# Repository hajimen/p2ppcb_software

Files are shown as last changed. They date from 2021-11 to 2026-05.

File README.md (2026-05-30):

# Maintenance mode

Now P2PPCB platform is maintenance mode.

You can still buy P2PPCB components, but they are not in stock of 
[DecentKeyboards Etsy shop](https://www.etsy.com/shop/DecentKeyboards).
Please ask me via Etsy system if you need them.

I will maintain P2PPCB platform until Jan 2027. If there is no demand until Jan 2027,
I will stop to maintain.

# P2PPCB platform overview

**P2PPCB platform** is a software / hardware complex for rapid prototyping of 3D-shaped PC keyboards,
offered by [DecentKeyboards](https://www.etsy.com/shop/DecentKeyboards).

With P2PPCB platform, you can design your own 3D-shaped keyboards, like this one:

NTCS

The above is not easy. It takes several hours by a highly skilled operator (me).

But the one below can be done in a few hours by a newbie who has a Windows PC (English) and a broadband connection, without any charge:

Starter Kit Bob

You can build your own design using a 3D printing service, P2PPCB components, and switches / keycaps / stabilizers / etc. as you like.

https://user-images.githubusercontent.com/1212166/204074347-09d51a74-aeb3-4d89-92ee-5701aa64c457.mp4

## No soldering

P2PPCB platform uses single IDC contacts for wiring, as shown here:

Single IDC Ccntacts

Simply push a wire into a contact by a special hand tool.

Special hand tool

Kyocera AVX provides them. Details can be found here:
<https://www.kyocera-avx.com/products/connectors/wire-to-board/single-idc-contact-22-28-awg-9176-400/>

Point-to-point wiring with PCB without soldering, hence the name is "P2PPCB".

Point-to-point wiring is much more flexible than ordinary PCB. 3D-shape is the best example.
Rapid and easy prototyping of ordinary keyboards is also a happy use.
With P2PPCB platform, you don't need to build a dedicated PCB for each design.
Just a 3D-printed frame, and the software helps your CAD operation a lot.

[Socket](https://www.aliexpress.com/item/32959301642.html) connects the switch to the PCB.
There is nothing to solder by yourself, even in the case of split keyboards.
(But if you need to connect a debugger, soldering is required.)

## All softwares are open-source or charge-free for hobbyists

- [keyboard-layout-editor.com](http://keyboard-layout-editor.com) : Open-source
- [Autodesk Fusion 360](https://www.autodesk.com/products/fusion-360/overview): Charge-free for hobbyists
- [P2PPCB Composer F360](https://github.com/hajimen/p2ppcb_software/tree/main/p2ppcb_composer_f360): Open-source
- [QMK firmware](https://qmk.fm/): Open-source

As long as your project stays on a PC screen, there is no charge.

## Switch LED is available

Switch LED

Up to six per keyboard usually.

## MX / Choc V1 / Choc V2 / Gateron LP switches are available

Available switches:

- MX ([Kailh MX](https://www.aliexpress.com/item/32966071689.html) and many other Cherry MX compatible)
- [Kailh Choc V1](https://www.aliexpress.com/item/32959996455.html)
- [Kailh Choc V2](https://www.aliexpress.com/item/4000803757746.html)
- [Gateron LP](https://gateron.com/collections/low-profile-series)

Available stabilizers:

- Cherry-style plate-mount (for MX)
- Coaster (for MX)
- [Kailh Choc V1 stabilizer](https://www.aliexpress.com/item/33039182740.html) (for Choc V1)
- [Choc V2 clip type stabilizer](https://keeb-on.com/products/stabilizer-chocv2) (for Choc V2)
- [Gateron LP](https://gateron.com/products/gateron-low-profile-plate-mounted-stabilizer?VariantsId=10478)

# P2PPCB Composer F360

**P2PPCB Composer F360 (PC0)** is an add-in of Autodesk Fusion 360 (F360) on Windows PC and Mac.
More details can be found here: <https://github.com/hajimen/p2ppcb_software/tree/main/p2ppcb_composer_f360>

## Keycaps

PC0 handles keycaps to check interference and to help your design process.
The following are available on PC0. You can of course put other keycaps on your 3D-printed keyboards.

- XDA (9.5 mm height. CAUTION: There are a lot of "XDA" profiles in the market)
- DSA
- Cherry profile
- OEM profile
- [Kailh Choc V1](https://www.aliexpress.com/item/32979973961.html)
- [Junana MX](https://www.etsy.com/listing/1636124875/blank-junana-mx-keycaps) (New profile from DecentKeyboards)

Only Junana MX can mate with Choc V2 or Gateron LP, normally. In fact DSA 1u can do it in a deep geeky way.
Dig into `P2PPCB Internal/Depot Parts mU0jU/Cap DSA 1u.*` component of your F360 file, and find what to do.

# P2PPCB Components

There are many dedicated components for P2PPCB platform. It also requires general-purpose parts like switches and keycaps.

[DecentKeyboards](https://www.etsy.com/shop/DecentKeyboards) is selling P2PPCB components.
General-purpose parts are at your own choice.

## Mainboard

A mainboard connects the USB to the matrix wires. Comparison chart of the three mainboards:

| |Alice|Bob |Charlotte|
|----|-----|----|---|
|Cost|Bad  |Cheapest|Good |
|Size|Bad  |Smallest|Good |
|Split Keyboard|USART|N/A |Qwiic|
|Qwiic|Yes  |No |Yes  |
|Matrix Size|8x24 + 2x6|12x16|12x16 + 2x3|
|Matrix Wire|Dupont|30 pin ribbon|36 pin ribbon|
|Switch LED|12 |0 |6  |
|Underglow|Yes|No|No|
|USART|Yes|No|No|
|Complexity|Bad|Simplest|Good|

### Alice

Alice

I don't recommend **Alice** in most cases. It is only good for R&D labs that have a high precision and large size 3D printer.
If you use a 3D printing service, go with Bob or Charlotte.

Alice harness kit

Alice accepts female Dupont wire as matrix wire. It is cheaper and more convenient than **Bob** / **Charlotte**'s IDC ribbon cable.
A Dupont wire is not very reliable, but sufficient for trial-and-error iterations of a design process.
A harness kit (the picture above) is available for high reliability, but it is quite expensive.

You might think that IDC ribbon cable is available for Alice. I thought so, too.
But 1.27 mm pitch ribbon cable (common thing) is too thick for a single IDC contact. I could not make it reliable.
(This is a big reason why I made Bob and Charlotte.)

### Bob

Bob

[Purchase from DecentKeyboards](https://www.etsy.com/listing/1609788806/mainboard-set?variation0=4138702941)

**Bob** is the smallest and cheapest but lacks a lot of features.
You can configure most things with VIA <https://www.caniusevia.com/>.
With Bob, you can live without QMK firmware configuration in most cases.

### Charlotte

Charlotte

[Purchase from DecentKeyboards](https://www.etsy.com/listing/1609788806/mainboard-set?variation0=4138702945)

If you need a split keyboard / switch LED / Qwiic connector, **Charlotte** is recommended.
If you go with Charlotte, QMK firmware is a must.

(You may wonder how Charlotte uses I2C for split keyboards. I implemented I2C slave mode
that ChibiOS doesn't have. The code is RP2040 only, sorry.)

## Matrix wire

36-pin 1.00 mm pitch IDC ribbon rainbow cable

[Purchase from DecentKeyboards](https://www.etsy.com/listing/1623836437/matrix-wire)

A matrix wire connects a mainboard to contacts.

Alice accepts a female Dupont wire as a matrix wire. It is a general-purpose part, not a P2PPCB component.
A harness kit for Alice is available as a P2PPCB component, but it is not recommended in most cases.

Bob and Charlotte accept 1.00 mm pitch IDC ribbon rainbow cable as matrix wire. This pitch is not very common.
These are P2PPCB components. When you build a keyboard, peel off the bonds of wires (easy to peel)
and use them as single wires.

## Contact-to-socket assembly

MX, Choc, and Gateron LP socket are available. LED and normal for each socket. So:

- MX LED
- MX normal
- Choc LED
- Choc normal
- Gateron LP LED
- Gateron LP normal

are available.

Contact-to-socket

[Purchase from DecentKeyboards](https://www.etsy.com/listing/1609640258/normal-contact-to-socket-assembly-20pcs)

(You may wonder how an LED and a switch both can be driven / read by only one pair of wires.
By utilizing the forward voltage (Vf) of LEDs. Below its Vf, an LED has no current flow (no light, of course).
We can read a switch by applying a voltage lower than the Vf. To drive an LED, a resistor is connected in series with the switch.
Even when the switch is closed, the resistor produces enough voltage to drive the LED which is connected
in parallel to the switch-resistor. Reading and driving are multiplexed by time division in high frequency like PWM.)

### Single IDC contact push mount

Single IDC Contact Push Mount

To push a wire to a single IDC contact, use this mount. Insert the cuboid end into the switch hole of a frame.
You can get this component by printing the F3D file: `p2ppcb_component_reference/contact-to-socket/Single IDC Contact Push Mount.f3d`.

## Split keyboard kit

Qwiic-to-TRRS

[Purchase from DecentKeyboards](https://www.etsy.com/listing/1609781062/split-keyboard-kit)

Charlotte uses Qwiic (3.3V I2C with Vdd on JST-SH 4-pin connector) for split keyboards.
The Qwiic-to-TRRS assembly is available as a P2PPCB component. TRRS cable is a general-purpose part.

P2PPCB split keyboard kit contains:

- Qwiic-to-TRRS assembly: 2 pcs
- TRRS cable 50 cm: 1 piece

(No P2PPCB component for USART split keyboards of Alice. Connect by female / female Dupont wire or solder a terminal of your own choice.)

You can use the 3D model of TRRS terminal by **Place Misc** command of PC0.

## Adjustable foot kit

Foot spacers

Height comparison

[Purchase from DecentKeyboards](https://www.etsy.com/listing/1623947013/adjustable-foot-kit)

Even with 3D-shaped keyboards, height-adjustable feet are indispensable for many reasons.
Rubber sole is also indispensable. P2PPCB platform has its own foot kit.

# Qwiic-to-FFC adapter kits for trackpad modules

You can embed trackpad modules to your keyboards. Available trackpad models:

- Azoteq ProxSense TPS43 / TPS65 after Dec 2022
- (With light modification) Cirque TM023023 / TM035035 / TM040040

A Qwiic-to-FFC adapter kit contains a Qwiic-to-FFC adapter and the FFC.

Qwiic-to-FFC adapter for Azoteq TPS43/65 after Dec 2022, with overlay for TPS43/65

[Purchase from DecentKeyboards](https://www.etsy.com/listing/1708346877/qwiic-to-ffc-adapter-kit-for-azoteq)

Qwiic-to-FFC adapter for Cirque 12-pin trackpad

[Purchase from DecentKeyboards](https://www.etsy.com/listing/1708366579/qwiic-to-ffc-adapter-kit-for-cirque-12)

The trackpad modules above have FFC connectors. The Qwiic-to-FFC adapters
connect the trackpad modules to the mainboards of P2PPCB.

You can use the 3D models of the adapter and the trackpad modules by **Place Misc** command of PC0.

The Qwiic-to-FFC adapters have DR or RDY contact. They are for power saving. QMK doesn't need them.
In the future, they may be good for wireless keyboards.

# Starter kit

P2PPCB platform requires so many parts to build a real keyboard.

- Special hand tool for single IDC contact (special bit and common handle)
- Mainboard (with screws)
- Contact-to-socket assembly
- Single IDC contact push mount
- Matrix wire
- Adjustable foot kit
- Key switch
- Keycap
- 3D-printed frame
- One Philips and one flat screwdriver :-)

In these parts, difficult-to-reuse is only matrix wire and frame. You can reuse contact-to-socket assembly
up to three times (according to Kyocera AVX. I guess much more actually).

So DecentKeyboards combined them into P2PPCB Starter Kit (except screwdriver). Just by getting this kit,
you can build and test a P2PPCB-based keyboard by hand.

[Purchase Starter Kit Bob from DecentKeyboards](https://www.etsy.com/listing/1631407997/starter-kit-bob)

[Purchase Starter Kit Charlotte from DecentKeyboards](https://www.etsy.com/listing/1617242134/starter-kit-charlotte)

# Technical Details

This repository contains a lot of technical details about P2PPCB platform. You'll need it if you want to go deep.

`p2ppcb_component_reference`: P2PPCB component

`p2ppcb_starter_kit_reference`: P2PPCB Starter Kit

# Discussions

If you have any questions, please feel free to join the discussions:
<https://github.com/hajimen/p2ppcb_software/discussions>

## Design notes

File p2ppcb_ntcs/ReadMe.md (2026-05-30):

# P2PPCB NTCS keyboard overview

NTCS left

NTCS right

**P2PPCB NTCS** keyboard is a reference design of P2PPCB platform. It demonstrates the ability of P2PPCB platform 
to produce elaborate and real-world (not mass-produced) products.

The "NTCS" stands for "Near TKL Conservative Split". 
It is conservative because it accepts ready-made keycap sets (should be row-independent uniform profile like XDA or DSA) 
for common US-ASCII TKL (87-keys) keyboards. It hides several obsolete keys (Pause, Scroll Lock, Print Screen, Caps Lock, Insert, Menu)
under QMK layer, but all other TKL keys are there, so "Near TKL".

You can use it as a reference for your design, as a test specimen to evaluate P2PPCB platform in the real world, 
or just for fun.

# Covered and naked style

P2PPCB platform is mainly for rapid prototyping, so it adopts "naked style" as its usual products. This is an example of the naked style:

Naked style 1

Naked style 2

In naked style, the wires are exposed. It is good for rapid prototyping because it is enough for testing in a lab.
Making a cover is a waste of time and money in this case.

The real world requires a covered style. Once you are confident with your own design in your lab with the naked style, you can bring it 
into the real world with the covered style.

Covered style

P2PPCB NTCS keyboard shows an example of covered style. The structure is thoroughly tested by the real 3D printing results.
I recommend you to imitate the structure on your own design.

# How to assemble

If you feel hard to prepare all parts / components and assemble them, please ask me via email.
The price is $1000 without switches, keycaps, and the shipping charge.

## Parts list

- P2PPCB mainboard Charlotte set: 2 sets
- P2PPCB matrix wire for Charlotte: 2 pcs
- P2PPCB adjustable foot kit: 4 sets
- P2PPCB split keyboard kit: 1 set
- P2PPCB MX normal: 82 pcs of fragment
- P2PPCB MX LED: 2 pcs of fragment
- M2.6 x 7 mm pan-head self-tapping screws for plastic: 16 pcs
- Cherry MX compatible key switch: 84 pcs
- Keycap set, row-independent uniform profile, common US layout TKL (87-key): 1 set
- Translucent 1u keycap: 2 pcs
- Blank 1u keycap: 2 pcs
- Cherry-style plate mount stabilizer for 2u: 4 pcs
- P2PPCB NTCS frames and covers, printed by Somos LEDO 6060: 1 set
- (Optional) Kyocera AVX single IDC contact accessory cap 609176001415000: 168 pcs

## Precision check

Precision checker

You can find these indentations on the covers of NTCS. They are precision checkers for verifying the precision of 3D printing results.
Get an M3 screw or a 3.0 mm drill bit, and try to push it (chuck side or tail) into a gap between three indentations, 
as shown in the figure below.

Precision check

Seven indentations consist a section, and two sections are paired side-by-side. 
The diameter of the green translucent cylinder shown in the figure above is 2.9 mm, or 3.1 mm in the drawings. 
One of the section of a pair is 2.9 mm, and the other is 3.1 mm. Therefore, if a 3D printing 
result is enough precise, you can easily insert a 3.0 mm cylinder into all six gaps of the 3.1 mm section, 
and feel difficult to insert into any gaps of the 2.9 mm section.

The section pairs are installed on the XY, XZ, and YZ planes of a cover because many 3D printers have anisotropy. 
If your 3D printing result fails the test, you may face a problem during assembling. Actually 2.9 mm gaps
can accept 3.0 mm (3D printers tend to have minus tolerance, -20 to -50 μm), but all 3.1 mm gaps must accept 3.0 mm.

## Writing firmware

At the time of shipment, the mainboards' firmware is starter kit's. You need to write the NTCS firmware to the mainboards.
The firmware file is `p2ppcb_charlotte_ntcs.uf2` in this directory.

Unplug the USB, press the BOOTSEL button, and plug USB. You'll find the `RPI RP2` drive on your PC.
Copy the firmware file into the drive. The mainboard will automatically reset itself and become NTCS.

You should write it on both left and right, of course.

## Single IDC contact accessory cap

For P2PPCB starter kit, there are no covers on single IDC contacts. This is reliable enough 
while the keyboard is in the lab. If you find a disconnection, just fix it with the tool.
It is quite rare.

But in the real world, sometimes "quite rare" is not enough. The accessory cap ensures the reliability. 
When you finish an operation test successfully, apply the caps on the contacts. Long nose pliers will help you.

CAUTION: Once you apply a cap, you cannot remove it without damaging the contact-to-socket assembly. 
Check the operation carefully before applying.

CAUTION: If you are using non-genuine matrix wire, the cap may not be applicable. 1.2 mm diameter is the upper limit of the thickness.
The peel-offed wire of a common ribbon cable (1.27 mm pitch) exceeds the limit.

## Tightening screws and warp correction

First of all: Please note that **3D printing material is fragile against small screws such as M2.6**. 
The tightening force should be much less than for normal screws. Just stopping the rattling is enough. 
It cannot withstand too many tightening-loosening iterations. 

I assume that you have already assembled a P2PPCB starter kit. There will be no hard part before
fastening the frame to the cover (please check the operation before fastening). 
The fastening is a bit tricky, because the design is the countermeasure of the warping of the 3D printing results.

Put the frame into the cover, and:

1. Put M2.6 x 7 mm screws into the holes of the cover wall. Don't tighten them, just screw them in a little.
2. Put a M2.6 x 7 mm screw into the hole in the center of the cover bottom. Tighten it mildly.
3. Make sure that the cover bottom is completely flat. If it is not flat, the feet will rattle. 
This is very common because 3D-printing results are always warped.
4. By pushing or pulling the frame to the cover, make the cover bottom flat, and tighten mildly the screws of the wall.

# How to use

The keycaps are row-independent uniform profile. So you can reallocate all 1u keycaps as you like.
Of course you can remap keycode using VIA. The draft definition file for VIA can be found here: 
<https://github.com/hajimen/p2ppcb_software/blob/main/p2ppcb_ntcs/via_keymap.json>

The left and right bodies both have a Micro USB type-B connector. You can choose one whichever you like and connect it to your PC.

The hole on the cover near the USB connector is for BOOTSEL button of Raspberry Pi Pico. You can press BOOTSEL button via the hole
to write new firmware.

The LED keys in front of the space keys are for Caps Lock / Scroll Lock indicator. 
I map LANG2 / LANG1 on them (useful keys for Japanese input) in QMK layer 0. 

The finger assignment shown in the figure below may look strange. 
The "Typing Method" says that you should press the "1/!" key by your pinky finger,
but I think this is outdated rubbish from the age of non-electric typewriters and professional typists. They didn't use wrist rests 
because they had to hit the keys with an adequate even force, like a pianist. If the hitting force is uneven, the thickness of the letters 
will be uneven. This was not considered the workmanship of a professional typist. So they hit the keys with their shoulders and arms, 
not with palms and fingers. In this case, the shortness of the pinky finger is not a 
problem because the upper arm moves and covers all the keys on a keyboard. 
Also, professional typists didn't develop sentences in front of a typewriter because there was a manuscript to type. 
No revising or editing, of course. In front of a typewriter, they just typed without stopping. 
There was no room for wrist rests, like on a piano.

Today we live on another planet. 
NTCS has built-in wrist rests. It doesn't assume shoulder-and-arm typing. Long fingers should press distant keys.

Finger Assignment

# The design process of NTCS

P2PPCB platform is for rapid prototyping. So I guess you are going to start a design process with it.
The F3D files show the final result, not the process. Let's see the story.

## Starting point 1: TRON keyboard TK1

The 1980s was the golden age of bizarre keyboards. The pinnacle is TRON keyboard TK1, 1991.

TK1

Cited from SAKAMURA Ken, Keyboard Dangi 7, bit (1990) Vol. Dec.

TK1 has its long story. I only enumerate the ideas what I stole from it.

- 10° twist along front-back direction and built-in wrist rests

These two ideas are closely related. 10° twist along front-back direction requires uncommonly high-profile wrist rests 
because the keytop altitude of the inner area is much higher than common keyboards.
Built-in wrist rests can be uncommonly high-profile.

- Wedge-shaped gaps between keytops

My dear keyboard people, please stop filling a keyboard with keytops. This is a quite common mistake
in the industry. Key separation (the ability to press a key without interfering with other keys) is much more 
important than keytop largeness, and key separation requires gaps between keytops.
Your habit may say "Gaps between keytops are ugly". Please break that habit now.

NTCS's wedge angle is much sharper than TK1's. TK1's angle is more bizarre and attractive, but I've come to 
the conclusion that it is not good for typing.

- Small space key and Shift keys with thumbs

These ideas were very common even before TK1. Maltron's keyboard in 1980 had a small space key.
Fujitsu's "親指シフト" (Thumb Shift) keyboard in 1980 had Shift keys with thumbs (the space key was also small). 

- Arrow keys under the main cluster (right side only)

Symmetrical arrow keys are the great charm of TK1. I tried to mimic this by placing Home / End / PgUp / PgDn instead of 
red arrows on the left hand part, but when I tested the layout with several prototypes, I realized that this is a bad idea. 
All navigation keys should be assigned to the right hand, because the left hand should focus on copy / paste.

- How about other ideas?

As you can see, I didn't adopt many ideas in TK1. Symmetrical and column-staggered layout, 
built-in drawing tablet, 3-bank typewriter style shift (left and right Shift keys work differently), 
16 mm pitch, etc. Yeah TK1 is the pinnacle of the bizarre keyboards of the 1980s. 
I miss these ideas, but this is a design process.

## Starting point 2: Ready-made keycap set

I am running a custom keycap shop [DecentKeyboards](https://www.etsy.com/shop/DecentKeyboards). 
I can print any legends on white PBT blank keycaps. But such custom keycaps can distract 
attention from the capabilities of P2PPCB platform. NTCS is a reference design for P2PPCB platform, 
not an ultimate keyboard.

(Besides, an ultimate keyboard requires a new ecosystem. OS, applications, common practice, 
users, developers, hardware and its supply chain. 
TRON keyboard TK1 was a part of such a new ecosystem "BTRON", but it failed. From this experience, 
I think that an ultimate keyboard will not be profitable, not widely available, not even very good for most people in the real world, 
even if it is mass-produced and its price is around ordinary keyboards. An ultimate keyboard is like 
an exotic car. Its price may be several hundred times of ordinary products, but it is inferior to ordinary products 
in most respects, even without taking the price into account.)

Swapping keycaps is a great hobby. It is much harder with custom keycap-based keyboards. 
A ready-made keycap set is a great product of the existing ecosystem.

## Starting point 3: Keyboard shortcuts of Windows applications

Actually, I'm not a big fan of keyboard shortcuts. Of course I use them heavily, but because of that, 
my pinky finger hurt often (now I am free of the pain with NTCS). From a productivity standpoint, 
keyboard shortcuts are negligible IMHO. I use them just because I'm impatient with using a mouse.

Not all the people (including keyboard people) are so impatient. Prioritizing keyboard shortcuts is an important 
decision, because it completely changes the design.

For example, by prioritizing keyboard shortcuts, all modifier keys should be easy to press simultaneously, 
in any combination, with one hand.
(I think multiple pressing of modifier keys is 
a bad idea in the existing ecosystem. Commands should be invoked when the keys are released, just like mice and touchscreens. 
But NTCS is not an ultimate keyboard).
Because of this requirement, 
yet another modifier key (i.e. QMK layer) is hard to use heavily. Ctrl+Shift+F5 is a very familiar shortcut in Visual Studio, 
but if F5 is hidden by yet another modifier (YAM) key, Ctrl+Shift+YAM+5 should be easy to press. 
In Japanese typing, F7 is a very frequently used key. YAM+7 should be as easy to press as Shift+7. 
I think it is impossible to fulfill all of these requirements under all of the prerequisites above.

Under different prerequisites, heavy use of YAM key can be a good design because it can reduce the number of keys on a keyboard. 

## Starting point 4: Stateless (as far as I can)

I hate intangible states. The downfall of keyboards started when the latching mechanism of Caps Lock key was substituted by LEDs.
One-shot modifier of QMK is a kind of intangible states.

## Other ideas stolen from various keyboards

- Del key at the left edge

The idea comes from Symbolics keyboard (namely Space-cadet). The RUB OUT key is a legend.

- Esc key at the left top corner of the main cluster

This was common before the dominance of IBM Model M layout. I'd like to name HHKB as the resistance movement against
the dominance.

## Iteration 1

https://user-images.githubusercontent.com/1212166/207766975-fe80b625-9c89-4bb3-ab00-f115f13a7b42.mp4?raw=true

The first trial. Left hand only, naked style, custom keycap based. In this iteration, I didn't adopt the start point 2.

I got a lot of findings in this iteration. 

- Thumb keys should be tilted in the opposite direction of the other keys.
- Wrist rests should be uncommonly high-profile, because the keytop altitude of the inner area is 
much higher than common keyboards.
- Pinky finger keys should be more front.

## Iteration 2

https://user-images.githubusercontent.com/1212166/207769963-8871a65c-baf6-4fd5-8fc1-cc160b2b6ee9.mp4?raw=true

The first trial of the covered style. I adopted the start point 2 from this iteration.

- Small space key should be in front of V. Shift key should be the right neighbor of the space key.
- Q should be pressed by a ring finger.
- Thumb keys should be lower.
- Ctrl key should be a thumb key.

I don't mention the problem of the covered style. Just imitate the conclusion shown in the F3D files of NTCS.
And I don't mention the right hand part too. It will be redundant.

## Iteration 3

https://user-images.githubusercontent.com/1212166/207800112-49950f18-dee0-47fb-89b6-9756c5d27d19.mp4?raw=true

https://user-images.githubusercontent.com/1212166/207801987-bb7279e0-d1bd-43f7-8470-23f2b017d544.mp4?raw=true

The first trial of built-in wrist rests. I thought of taking a video at this time.
The material is SLA of WENEXT. Built-in wrist rests take up a lot of space,
and it makes 3D printing much more expensive.

- The position of the Alt key is not a good idea.
- Pressing the space key interferes with End key.
- The wrist rests are too long in front-back direction.
- Shift and Ctrl keys should be a bit further back.
- Ctrl key should be 1 mm higher.
- Q row of pinky finger section should be slightly higher for key separation.
- Tab key is too far for pinky finger.

## Iteration 4

https://user-images.githubusercontent.com/1212166/207805898-d4af1ae7-47c4-46dc-a097-f8915beb6a94.mp4?raw=true

https://user-images.githubusercontent.com/1212166/207806336-694a83c3-6f9b-410a-8993-eb757cfd567e.mp4?raw=true

- Shift key should be further front.
- LANG1 should be lower. Pressing the Ctrl key interferes.
- Symmetrical layout of arrow keys (Home / End / PgUp / PgDn - Left / Right / Up / Down) is a bad idea.

## Iteration 5

https://user-images.githubusercontent.com/1212166/207811766-837e6841-0c39-4954-b991-4490d437edb7.mp4?raw=true

https://user-images.githubusercontent.com/1212166/207813334-f48241b7-b52c-4ad7-b488-d3c9fbc1e20a.mp4?raw=true

In this iteration, the material is MJF PA12 black.

- Function keys interfere with my palm. The function key cluster should not tilt.

## Iteration 6

This is the last iteration worth mentioning. I have done many more, but the findings are trivial.
This iteration is not the final result, but it is close enough for the purpose of this story.

https://user-images.githubusercontent.com/1212166/207817193-05dbc5cd-c3d1-442c-9eca-ad06bcb6c566.mp4?raw=true

https://user-images.githubusercontent.com/1212166/207817925-683ccf40-5cc8-40d5-9adb-0121a6b742cf.mp4?raw=true

- The key angle surface should be finely tuned.

# How to imitate the structure of NTCS

It is far from straightforward. If you feel it is too tedious, please ask me. I can make a covered style 
from your naked style F3D file. It costs, of course.

The basic story is the Fill/Hole method. You should do the method manually to the cover.
In the F3D file of NTCS, on the object browser, expand `P2PPCB Internal/Foot Placeholders mU0jU/Foot A_FL:1/Foot_P:2/Bodies`.
You'll find a `Foot Fill Cover` body. `Cover Boss.*/Bodies` and `Adjust Boss.*/Bodies` also have bodies with such names. 

The **Regex Select** command will help you. You can see the results of the command 
in the "Selection Sets" of the object browser.

`P2PPCB Internal/Depot Parts mU0jU/Switch MX_P:1/Bodies/MF/Switch Fill.*` is a very important trick that is hard to 
comprehend. See the timeline of the F3D file step by step. The fill body of `Switch MX_P` is modified from the original 
before the **Fill** command is executed. The modification makes it possible to connect a bridge body to a switch 
fill body using the **Extrude** command.

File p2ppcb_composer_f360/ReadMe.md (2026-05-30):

# Maintenance mode

Now P2PPCB platform is maintenance mode.

You can still buy P2PPCB components, but they are not in stock of 
[DecentKeyboards Etsy shop](https://www.etsy.com/shop/DecentKeyboards).
Please ask me via Etsy system if you need them.

I will maintain P2PPCB platform until Jan 2027. If there is no demand until Jan 2027,
I will stop to maintain.

# P2PPCB Composer F360

**P2PPCB Composer F360 (PC0)** is an add-in of Autodesk Fusion (f.k.a. Fusion 360). It helps you to design your own keyboard
based on P2PPCB platform <https://github.com/hajimen/p2ppcb_software>.
I, DecentKeyboards <https://www.etsy.com/shop/DecentKeyboards>, provide P2PPCB platform.

DISCLAIMER: PC0 is slow for a large keyboard, so far. Initial **Load KLE** command can take several minutes.
Please start with making small studies and get a good grasp of the time consumption.

## Requirements: Just designing a Keyboard

- Windows PC or Mac

- Autodesk Fusion (F360) <https://www.autodesk.com/products/fusion-360/overview>

Autodesk Fusion is a proprietary 3D CAD. Autodesk generously offers charge-free plans for hobbyists so far.

Why does F360 mean Autodesk Fusion? Autodesk has rebranded Fusion 360 to Fusion in 2024. I am too lazy to follow
such pastime. I will call it Fusion 360 or F360 in all other places.

## Requirements: Building your own design

- A 3D printing service shop

As the printing material, HP Multi Jet Fusion (MJF) <https://www.hp.com/us-en/printers/3d-printers/products/multi-jet-technology.html> and
Somos® Ledo 6060 with sanding are well tested. In many cases, the latter is much cheaper.

IMPORTANT: The modeling assumes -20 to -50 μm tolerance. MJFs are made with this tolerance.
Ledo 6060s with sanding also. But Ledo 6060s **without sanding** has almost zero tolerance.
It doesn't fit. Choose "Surface finish: Sanding" if you use Ledo 6060.

There are many 3D printing service shops of MJF or Ledo 6060 in the world. 
[Shapeways](https://www.shapeways.com/) (North America and Europe), 
[DMM.make](https://make.dmm.com/) (Japan), [WENEXT](https://www.wenext.com/) (China),
[JLCPCB](https://jlcpcb.com/) (China) etc.
Pick a good one for you. I always use JLCPCB.

In most cases, 3D printing service shop will give you a warning about too thin walls. In most cases,
I don't recommend you to fix it. You must have the ability to identify real limits if you want to make
an elaborated design. Failure teaches success.

- P2PPCB components by DecentKeyboards <https://www.etsy.com/shop/DecentKeyboards>

PC0 is free, but P2PPCB components aren't :-).

- QMK Firmware <https://qmk.fm/>

You need your own firmware for your own design. PC0 will help you, but you need to be well informed about QMK.

P2PPCB mainboards require special code for their own hardware. I have prepared the codebase which handles the custom hardware:
<https://github.com/hajimen/qmk_firmware/tree/p2ppcb>. Fork the `p2ppcb` branch for your own design.

- Switches, keycaps, stabilizers

If you need custom printed keycaps for your own design, contact DecentKeyboards <https://www.etsy.com/shop/DecentKeyboards>.
I can make custom printed PBT keycaps. The total cost will be from about $30.

## Install

Download the latest release file from here: <https://github.com/hajimen/p2ppcb_software/releases>

Unzip the release file, run F360, click the **UTILITIES** tab -> click **+** -> Choose **Script or add-in from device**.
Select the `p2ppcb_composer_f360` directory in the unzipped release file.
Find `P2PPCB Composer F360` row and click the **Run** column's slide switch.
Now the "P2PPCB" tab should appear in the F360 menu.

## Overview of operations

1. Design your own key layout using KLE <http://www.keyboard-layout-editor.com/> and download the result in JSON. The file is a KLE file.

You can include QMK keycodes in your KLE file. The details are later.

2. Design the height/angle of the keys using F360 surface(s).

The F360 surface is a **skeleton surface**. You also need a F360 construction plane as a **layout plane**.
You can specify a **key angle surface** to create a stepped ("staircase") profile keyboard with uniform profile keycaps (DSA/XDA, etc.).
A **main surface** in the **Initialize** command dialog is both skeleton and angle.

You can get an example set of them from a scaffold set built in PC0.
Click the green **P2P/PCB** command icon in the P2PPCB tab and check the **Generate a scaffold set** checkbox in the command dialog.

https://user-images.githubusercontent.com/1212166/205190284-dbbb6a80-51aa-4bd7-b1e0-33d8e4ddc5c1.mp4

3. Start a P2PPCB project

Specify the main preference of key switch, cap, stabilizer, vertical alignment, etc.
The F360 file holds the preference.

You can run this command more than once.

https://user-images.githubusercontent.com/1212166/205190521-6bdee0ec-76c7-4ee5-b622-5411ba3257b6.mp4

4. Load KLE file

This can take several minutes for a large keyboard. F360 is not very suitable for P2PPCB Composer, but you don't want to pay
thousands of USD for CATIA, I guess.

5. Adjust any key

Of course you can move any key.

https://user-images.githubusercontent.com/1212166/205190738-955e6beb-f937-490e-a4c4-32c4ce18899b.mp4

You can also change the switch / cap / stabilizer / etc. of each key by using the **Change Key** command.
A bit bizarre behavior can occur in this command. See the video below.

https://user-images.githubusercontent.com/1212166/205191054-84a16ef2-c920-4fa9-a5d0-66a4c00a2914.mp4

6. **Fill** command

A generated frame doesn't have holes for keys yet. It is intended for the Fill/Hole method. The details are later.

https://user-images.githubusercontent.com/1212166/205191342-d7a71c5c-0b93-40e0-bb5d-ce35f1fff37d.mp4

7. Place mainboard and feet

You can run this command more than once. In most cases, you'll need to do many to place the feet.

In most cases, you will need to check for interference. It is extraordinarily slow. Use it carefully.

https://user-images.githubusercontent.com/1212166/205191446-48d868da-c83e-4557-8093-cd8c0a0816a8.mp4

8. Connect mainboard/feet bosses to a frame

You need to do this step through F360's features like loft, extrude, etc.

https://user-images.githubusercontent.com/1212166/205191579-d20d2189-508d-4ecd-a077-7d0353ef2241.mp4

9. **Hole** command

It creates a 3D printable solid body. Right-click the body in the browser, select **Save As Mesh**, select STL and click OK.
Send the STL file to your 3D printing service shop.

https://user-images.githubusercontent.com/1212166/205191677-80e63a34-99b5-444a-b3b5-ab5381502606.mp4

10. There is a thin wall? Oh...

3D printing cannot print thin walls. This often occurs in elaborated designs.
Some 3D printing service shops will accept such STL files if you take on all the risks. Some don't.
In that case, you have to remove them yourself (or ask another shop).

## Bridge and Fill/Hole - MF/MEV method

Switches, stabilizers, and screws should be fastened to their holes in the frame. Such holes must be free of obstructions,
otherwise parts will get stuck.

On the other hand, a frame itself is not so strict about defects. A frame should be strong, rigid,
and have essential areas to hold parts (such as internal screw threads).
Except for the essential areas, a frame can have some defects (voids) to some extent. Let's call such
non-essential areas which surrounding essential areas as "support areas".

PC0 adopts the Fill/Hole method to form a frame. Fill: create a solid. Hole: cut the solid.

How to create a solid? By connecting essential+support areas to each other. Where the key layout is dense,
the essential+support areas of the keys overlap. In this case, a simple "join" operation is sufficient.
Where the key layout is sparse, a **bridge** should connect the essential+support areas.
A bridge is a board parallel to the skeleton surface. 
By joining essential+support areas and a bridge, a solid is created. This is **Fill**.

Cutting the solid will be obvious. Holes must be void without obstructions,
so the Fill/Hole method doesn't allow fill-after-hole. This is **Hole**.

After Fill/Hole, we need to check that essential areas are filled without defects. The area that must be filled is **MF** (must-filled).

Hole areas don't always match their parts. Two parts cannot occupy the same area, but two insert paths can do. 
An insert path is occupied by a part during assembly, but is empty after the part is assembled.
A typical case is Cherry-style stabilizer's wire. Thus, a hole area can be larger than its part.
To know the area of a part itself, and to check the interference of parts with each other,
we need the **MEV** (must-exclusively-void) area in addition to the hole area.

To reduce the inference check computation, there is **Territory**. It declares the outer edge of fill-hole areas of a part.
You won't find it in normal operation.

**Placeholder** will be obvious. It is for developers only too.

## QMK keycodes in your KLE file

QMK keycodes can be found here: <https://github.com/hajimen/qmk_firmware/blob/p2ppcb/docs/keycodes.md>

By including the keycodes in your KLE file, P2PPCB can help you a lot. Just write the keycode (of layer 0) in the the front-left legend of the key.
The front-center legend is layer 1, and the front-right legend is layer 2. You can see the example in
`scaffold_data/starter-kit.json`.

## Keyboard matrix

Keyboard matrix: <https://github.com/hajimen/qmk_firmware/blob/p2ppcb/docs/how_a_matrix_works.md>

P2PPCB Bob/Charlotte uses S and D instead of row and col. QMK's row and col are independent of the current direction 
(ROW2COL and COL2ROW are both capable), but S and D are always S to D.

By assigning a matrix, and by including the keycodes in your KLE file, you can generate route data
(QMK keymap and wiring diagrams) and VIA keymap.
Without them, your life will be much harder. Use the **Assign Matrix** command and the **Generate Route** command in the P2PPCB tab.

Generating route data for split keyboards is not supported. You need to combine two keymaps into one by yourself.
The example is shown at <https://github.com/hajimen/qmk_firmware/blob/p2ppcb/keyboards/p2ppcb/charlotte/keymaps/ntcs/keymap.c>.

## Show all available caps

There are several `test.json` files in `p2ppcb_parts_data_f360/parameters/*/`. They are KLE files
and contain all available caps for each profile. Load them with the **Load KLE** command and see the result.

By inspecting `test.json` with KLE, you can grab how to specify row (in case of row-dependent profile) and special
caps like ISO Enter.

## F360's bug in parametric modeling

In some cases, parametric modeling is better than direct modeling, especially for making a cover. In parametric modeling mode, 
the placeholders of keys sometimes slip. This is F360's bug. In this case, use the **Sync Key** command.

## Advanced features and design

### **Place Misc** command

This command places a F3D file for miscellaneous parts and components.
So far this command is for:

- trackpads and its Qwiic-to-FFC adapters
- cover bosses

The F3D files should provide Placeholder / Fill / Hole / MF / MEV / Territory bodies.

After **Fill** command and before **Hole** command,
run the **Place Misc** command (should be found under the **PLACE PARTS**) in the P2PPCB tab.
It opens a file dialog. Choose an appropriate F3D file. Adjust the place. You can run the command
repeatedly on the same F3D file.

The inserted component should be found in **P2PPCB Internal/Misc Placeholders mU0jU**.
If you need multiple occurrences, copy it and paste.

Once the place is adjusted perfectly,
copy the Fill body to the root component and connect it to the frame body.
Hole will be done by running **Hole** command.

### **Regex Select** command

You can create a fully functional keyboard that has only a frame, no cover.
This is good enough for prototyping. But in some cases you may need a cover.

PC0 is not very helpful for making a cover, but there are some tools that can help you. 
With **Regex Select** command, you can make a F360 selection set by regex of the full path name of the entities.
You can do Fill/Hole method manually with this tool, without using **Fill** / **Hole** commands.

CAUTION: For a bug of Fusion 360, you cannot repeat **Search** now. If you failed to type right regex in the first trial,
press **Cancel** button and run **Regex Select** command again. You will see 'Selection Set n' after **OK** button.
You cannot name the created F360 selection set in the command dialog for the bug.
The bug: <https://forums.autodesk.com/t5/fusion-360-api-and-scripts/selectionsets-add-doesn-t-work-when-the-entity-is-proxy/m-p/11914208>

CAUTION: Unselect all objects before running the command.

### **Remove Undercut** command

Covers should be assemblable with their frames. You will encounter undercuts by running **Combine** command.
They will make a cover impossible to assemble.
To remove undercuts, run **Remove Undercut** command, select surfaces and a cover body.

### **Set Attribute** and **Check Key Assembly** commands

See the tooltips for each command. Creating a part's data requires deep knowledge, including F360's bug.
You should be a developer of PC0 if you want to create a part's data.

# For developers

If you are familiar with F360 add-in development, you'll notice that PC0 uses a bunch of bizarre hacks.
Let's see the hacks.

## Regression tests

The F360 script in `composer_test` runs regression tests. Please take a close look at `sys.path.append()` and `reimport.py`
hacks.

Convenient command launchers for debugging are available in `composer_test`. See the code.

`test_generate_route` is quite slow while the VSCode debugger is attached. I don't know why.

## Lazy binding through surrogate

From the end of a create event to the end of an execute event, the F360 command cannot import F360 components. 
Importing should be done in a create event handler or after an execute event.
Importing in a create event handler breaks the cancel button behavior (I did it in the **Load KLE** command). 
Importing after an execute event is done by F360 custom event: <https://help.autodesk.com/view/fusion360/ENU/?guid=GUID-EC785EB6-22A8-4932-B362-395262D802CF>

Anyway, F360 cannot import anything while a command dialog is displayed.
We need to build/manipulate an object tree before the objects become available.
In other words, we need lazy binding. So I adopted the surrogate method.
Objects-in-the-future are represented by surrogates.
After importing, the surrogates are replaced by real objects.

## Magic string 'mU0jU'

F360 doesn't allow name collision of F360 components. All F360 components should have unique name.
To avoid name collision with user's components, I add magic string 'mU0jU' to most components' name.
(The exception is 'P2PPCB Internal'.)

## Homebrew's Python dependency in macOS

This is a long story.

PC0 depends on Chromium Embedded Framework (CEF) for keytops' image from KLE.
Chromium requires multi process usually, but it still has single process mode.
The mode is not supported nor maintained, but it still works well accidentally.
PC0 depends on single process mode for a good reason. Please look at
[cef-capi-py](https://github.com/hajimen/cef-capi-py) about it.

CEF single process mode works well accidentally.
In macOS, python.org's Python is not in the case.
F360's embedded Python is locked by Team ID and cannot accept CEF.
So we need Homebrew's Python.

## How to build `app-packages-win_amd64` (Windows)

Prepare venv with python.org's `python.exe`.

```powershell
python -m pip install --upgrade pip
pip install -U setuptools wheel build
mkdir repos
cd repos
git clone https://github.com/hajimen/p2ppcb_software
cd p2ppcb_software/p2ppcb_composer_f360
pip install ../p2ppcb_parts_resolver -r requirements.txt -t app-packages-win_amd64
```

## How to build `app-packages-macosx_*` (Mac)

Use Homebrew's Python 3.12 because Mac F360's embedded Python lacks `pip` module.
If you run on Apple Silicon, you can choose Intel or Apple Silicon by `arch` command.
It is true for F360 itself.

Architecture independent part:

```bash
python -m pip install --upgrade pip
pip install -U setuptools wheel build
mkdir repos
cd repos
git clone https://github.com/hajimen/p2ppcb_software
cd p2ppcb_software/p2ppcb_composer_f360
```

Architecture dependent part:

```bash
tag='macosx_11_0_x86_64'  # or 'macosx_11_0_arm64'
pip install ../p2ppcb_parts_resolver -r requirements.txt -t app-packages-$tag
```

# Further development

PC0 has been improved over the past few years. I believe that PC0 is already good enough to design good prototypes.

I am thinking about the future of F360.
In my opinion, rebranding (Fusion 360 to Fusion) is a bad sign of the business.
Recent decal API bugs were quite easy to find, but shipped in the product.
I can't help but doubt F360 is going to die. So now I am reluctant to invest much more on F360.
For the time being, I will continue bug fixing and following of F360 update, but no exiting new feature will not arrive.

## F360's bugs that can annoy you or get you stuck

In some cases, interference check doesn't work:
<https://forums.autodesk.com/t5/fusion-360-support/obvious-interference-was-not-detected/m-p/10633251>

Attributes of native objects can be destruct by some irrelevant operations: 
<https://forums.autodesk.com/t5/fusion-360-support/attributes-of-native-objects-corrupt-by-removing-a-component/m-p/11909404>
You cannot import `P2PPCB Internal` component from other files for this reason. Import will corrupt attributes.

Intel Mac F360 has a bug in floating point operation:
<https://forums.autodesk.com/t5/fusion-360-api-and-scripts/python-bug-of-ieee-754-subnormal-number-on-intel-mac/td-p/12133211>
I think we should forget Intel Mac. It is going to be obsolete.

A component by Insert Derive goes wrong about decal:
<https://forums.autodesk.com/t5/fusion-360-support/a-component-by-insert-derive-goes-wrong-about-decal/m-p/11913925>

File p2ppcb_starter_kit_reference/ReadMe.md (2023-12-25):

# P2PPCB Starter Kit Bob / Charlotte

P2PPCB Starter Kit Bob / Charlotte are starter kits of P2PPCB platform. You can test the real 
quality and experience of P2PPCB platform through these kits.

## How to assemble

### 1. Prepare tools at your own

Hand tools:

- Philips screwdriver, PH1 size
- Flat screwdriver, 3.5 mm wide, 0.6 mm thick, on the edge (smaller is OK)
- Scissors or cutting pliers
- (Optional) Key switch puller
- (Optional) Digital multimeter

Hand tools

VIA: <https://www.caniusevia.com/>

### 2. Check the contents of the kit

Please check the contents of the kit with the included paper manuals.

### 3. Assemble contact-to-socket assemblies to the frame

DISCLAIMER: The videos show gray frame (MJF). The actual product is white (Somos Ledo 6060).

Tear a fragment of a contact-to-socket assembly from a full board.

https://user-images.githubusercontent.com/1212166/223646746-8ab56e6a-60d3-4587-8ffc-27e4f80802d5.mov

Insert the fragment into the hole in the frame.

CAUTION (Charlotte): Look at the wiring diagram! There is an LED fragment. Don't insert 
the normal fragment into the hole.

https://user-images.githubusercontent.com/1212166/223647008-41a2cce3-f3a8-4095-b10f-7d3f8a6ce913.mov

Push it into the hole with the flat screwdriver.

https://user-images.githubusercontent.com/1212166/223648865-bf569a75-6fc2-442b-8305-fc646b1283ee.mov

The result should be like this:

https://user-images.githubusercontent.com/1212166/223649365-13185463-47a5-4ad2-a7eb-a47b0a8cba95.mov

### 4. Assemble a mainboard to the frame

Pay attention to the direction.

https://user-images.githubusercontent.com/1212166/223650886-23f14d98-9855-4501-9a1c-a5af57097b62.mov

**CAUTION: Somos Ledo 6060 (the material of the frame) is fragile against small screws!** 
The tightening force should be much less than for normal screws. Just enough to stop rattling. 
It cannot withstand too many tightening-loosening iterations.

### 5. Put matrix wire to the mainboard

### 6. Peel the ribbon cable and cut the unused wires

Look carefully at the wiring diagram on the paper manual. If you feel hard to read it, use the digital images below.

- Starter Kit Bob: <https://github.com/hajimen/p2ppcb_software/blob/main/p2ppcb_starter_kit_reference/bob/wiring_D.png> <https://github.com/hajimen/p2ppcb_software/blob/main/p2ppcb_starter_kit_reference/bob/wiring_S.png>
- Starter Kit Charlotte: <https://github.com/hajimen/p2ppcb_software/blob/main/p2ppcb_starter_kit_reference/charlotte/wiring_D.png> <https://github.com/hajimen/p2ppcb_software/blob/main/p2ppcb_starter_kit_reference/charlotte/wiring_S.png>

### 7. Install wires into the contacts

Again, look carefully at the wiring diagram. But it is difficult. So the kit bundles two 
matrix wires :-).

https://user-images.githubusercontent.com/1212166/223652054-34629ded-7a83-4f41-a15c-5276e1920c53.mov

The jig helps you.

https://user-images.githubusercontent.com/1212166/223654861-1e51b0ce-4438-439f-9aec-14645ebf921c.mov

If you find that you go wrong, carefully pull out the wire, and strengthen the damaged points of the wire 
with Scotch tape or something.

Damaged wires will unexpectedly withstand tension, but are vulnerable to bending. This is true for normal installed points.
Don't bend wires at contacts.

### 8. Assemble key switches to the frame

Just push it.

https://user-images.githubusercontent.com/1212166/223880715-38a6497c-7b95-4a4e-988e-679835631a97.mov

It may look easy, but sometimes it fails like below. Please make sure that the leads of the key switches are straight before assembling.

Bad switch

### 9. Assemble feet to the frame

https://user-images.githubusercontent.com/1212166/223882839-7949211d-c44f-41d8-993c-a2fe876bee1c.mov

### 9. Check the operation with VIA

Load the draft definition file of your mainboard into VIA.

- Starter Kit Bob: <https://github.com/hajimen/p2ppcb_software/blob/main/p2ppcb_starter_kit_reference/bob/via_keymap.json>
- Starter Kit Charlotte: <https://github.com/hajimen/p2ppcb_software/blob/main/p2ppcb_starter_kit_reference/charlotte/via_keymap.json>

If you find non-operating key switches, check the wire-to-socket conduct. If it fails, press the contact again with the tool.
Otherwise, pull the key switch off and look at the contacts.

### 10. Assemble feet to the frame

Again, **CAUTION: Somos Ledo 6060 (the material of the frame) is fragile against small screws!** 
The tightening force should be much less than for normal screws. Just enough to stop rattling. 
It cannot withstand too many tightening-loosening iterations.

For the combination of screws and spacers, please refer to the paper manual included with the foot kit.

### 11. Install keycaps to the key switches

Just push it to the switch. In Charlotte, OSM-Ctrl is a translucent keycap.

Starter-Kit-Bob

## How to use

### Inspecting the F3D file to compare with the real object

Prepare [Autodesk Fusion 360](https://www.autodesk.com/products/fusion-360/overview) on your 
Windows PC or Mac (just for the inspection, Mac is OK, non-English language is OK), and open the F3D file below.

- Starter Kit Bob: <https://github.com/hajimen/p2ppcb_software/blob/main/p2ppcb_starter_kit_reference/bob/Starter Kit Bob.f3d>
- Starter Kit Charlotte: <https://github.com/hajimen/p2ppcb_software/blob/main/p2ppcb_starter_kit_reference/charlotte/Starter Kit Charlotte.f3d>

`P2PPCB Internal:1` in the object browser is an important one. Expand it and inspect it. Toggling the eye icons is also useful.

### Compiling and modifying the firmware

VIA can configure almost everything about Bob. About Charlotte,
you will need your own firmware for your own design.

The codebase is here: <https://github.com/hajimen/qmk_firmware/tree/p2ppcb>
`git clone -b p2ppcb https://github.com/hajimen/qmk_firmware` and see `keyboards/p2ppcb/charlotte`.

### Swapping and testing key switches

Somos Ledo 6060 frames have inherent stiffness and acoustics. They are very different from them of steel, alloy, or FR-4 (common PCB).

### See 3D printing quality, precision, and tolerance

You can see the overall quality by your eyes and fingers.

There are indentations on the frame, as shown in below:

Precision checker

These indentations are precision checkers for verifying the precision of 3D printing results.
Get an M3 screw or a 3.0 mm drill bit, and try to push it (chuck side or tail) into a gap between three indentations, 
as shown in the figure below.

Precision check

Seven indentations consist a section, and there are two sections per XY, XZ, and YZ planes. 
The diameter of the green translucent cylinder shown in the figure above is 2.9 mm, or 3.1 mm in the drawings. 
One of the section of a pair is 2.9 mm, and the other is 3.1 mm. Therefore, if a 3D printing 
result is enough precise, you can easily insert a 3.0 mm cylinder into all six gaps of the 3.1 mm section, 
and feel difficult to insert into any gaps of the 2.9 mm section.

The section pairs are installed on the XY, XZ, and YZ planes of a frame because many 3D printers have anisotropy. 
If your 3D printing result fails the test, you may face a problem during assembling. Actually 2.9 mm gaps
can accept 3.0 mm (3D printers tend to have minus tolerance, -20 to -50 μm), but all 3.1 mm gaps must accept 3.0 mm.

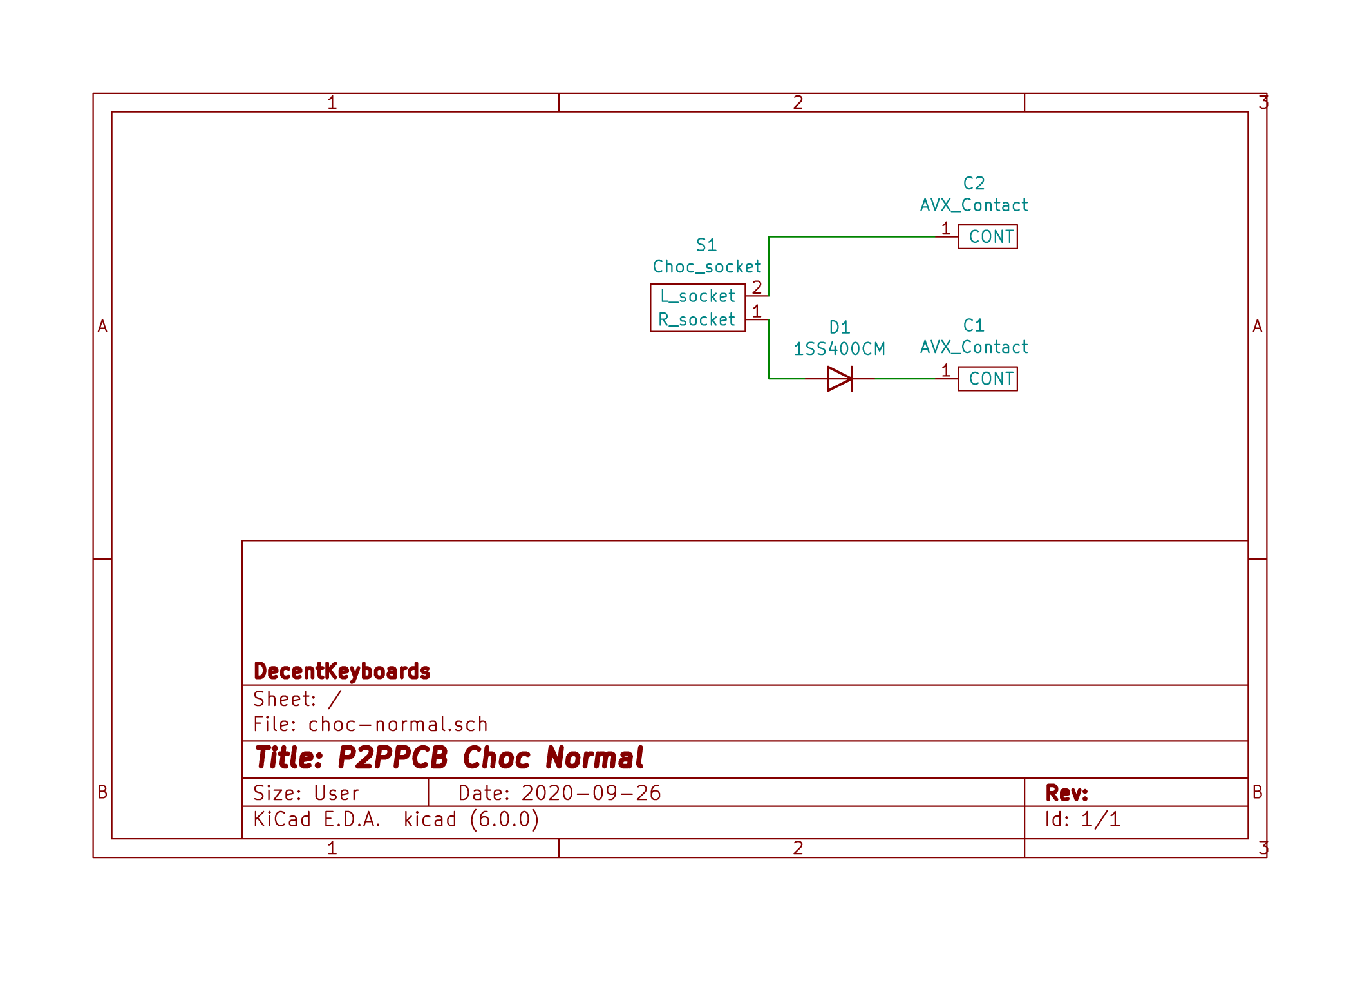
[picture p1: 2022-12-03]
p2ppcb_component_reference/contact-to-socket/schematic-normal.png

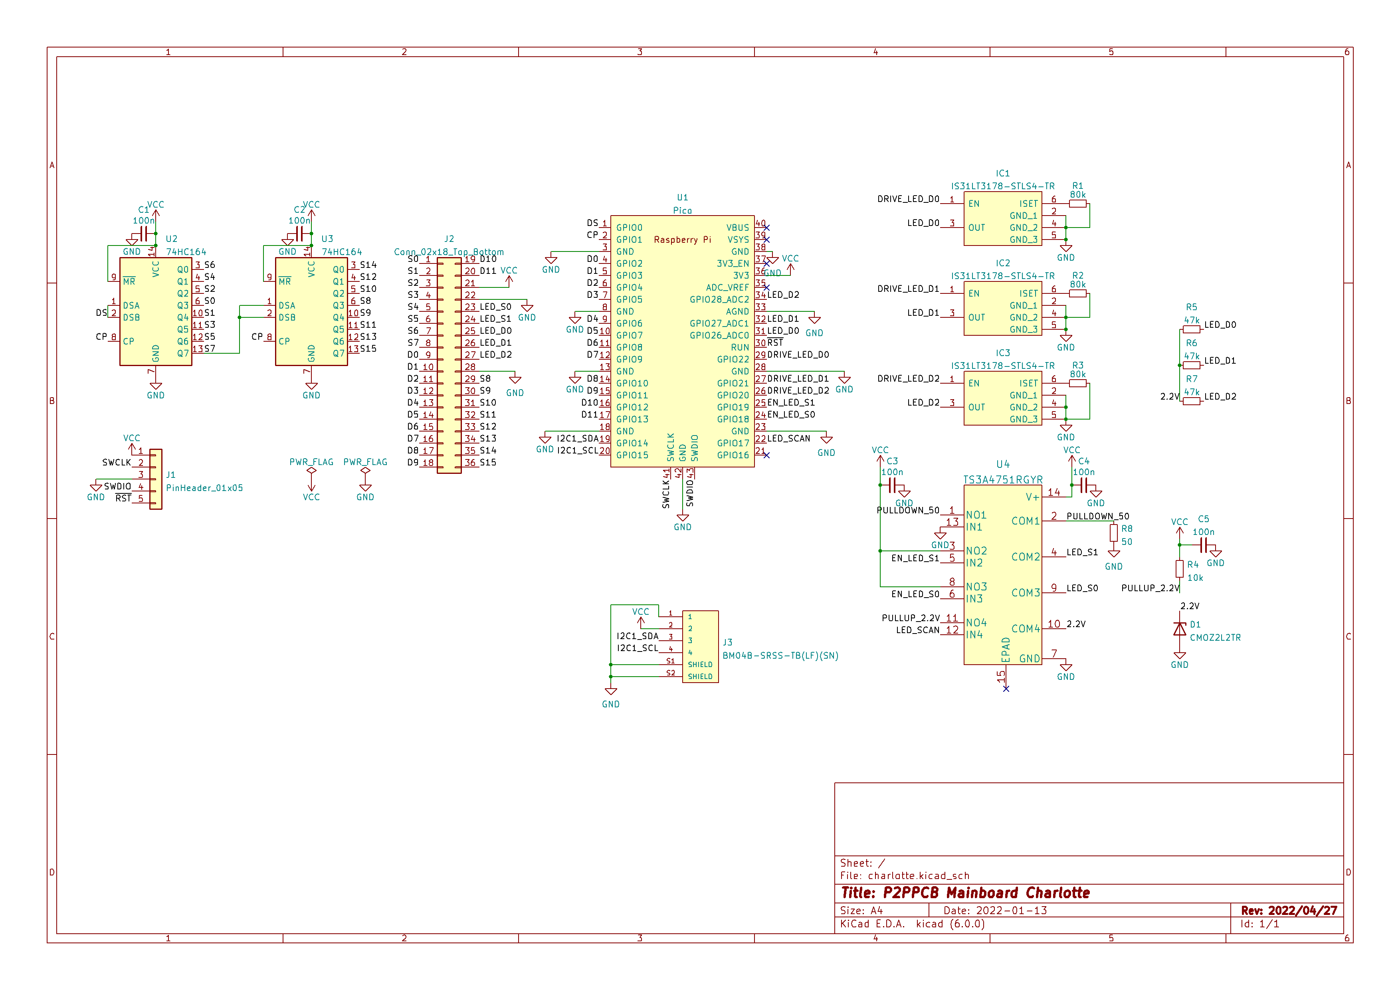
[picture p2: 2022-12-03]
p2ppcb_component_reference/charlotte/schematic.png

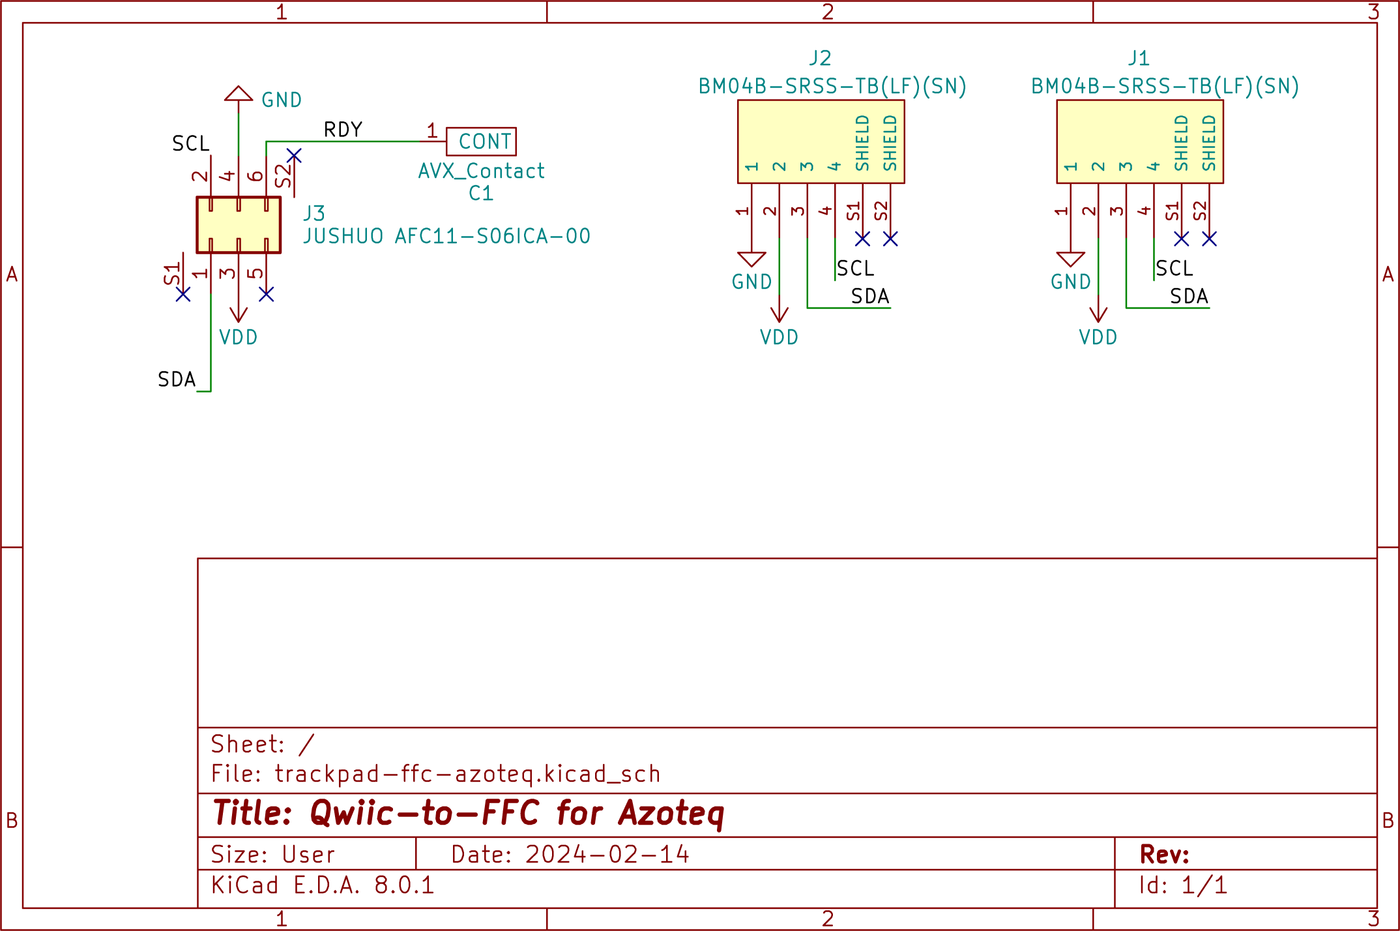
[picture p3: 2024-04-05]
p2ppcb_component_reference/qwiic-to-ffc/schematic-azoteq.png

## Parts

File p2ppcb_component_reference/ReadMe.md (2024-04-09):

# P2PPCB component reference

Mainly it contains schematic diagrams of the components.

# Mainboards

The dimension is shown in `p2ppcb_composer_f360/*.f3d`.

## Alice

- MPU: STM32F072C8U6
- USB type-C
- All IDC terminals are shrouded headers, 2.54 mm pitch.

## Bob / Charlotte

- MPU: RP2040
- Micro USB type-B
- The IDC terminal is a shrouded header, 2.00 mm pitch.

Bob's shrouded header: <https://lcsc.com/product-detail/IDC-Connectors_Wcon-3111-30SG0BK00T1_C783804.html>

Charlotte's: <https://lcsc.com/product-detail/IDC-Connectors_Wcon-3111-36SG0BK00T1_C920868.html>

- The pin header J1 for debugger is not implemented. Solder 1x5 pin header if you need it.

# Matrix wire

## Wire harness for Alice

Length: 1 m

Connector: <https://www.digikey.com/en/products/detail/hirose-electric-co-ltd/HIF3BA-30D-2-54C-63/12758629>

## IDC ribbon cable for Bob / Charlotte

Length: 60 cm

Connector of Bob: <https://lcsc.com/product-detail/IDC-Connectors_Wcon-5222-30YPS0BW01_C843027.html>

Connector of Charlotte: <https://lcsc.com/product-detail/IDC-Connectors_span-style-background-color-ff0-Wcon-span-5222-36YPS0BW01_C843029.html>

# Contact-to-Socket assembly

Single IDC contact: <https://www.digikey.com/en/products/detail/avx-corporation/709176001443006/3074530>

LED: <https://www.digikey.com/en/products/detail/lite-on-inc/LTST-C230KGKT/386855>

Diode: <https://www.digikey.com/en/products/detail/rohm-semiconductor/1SS400CMT2R/10495190>

# Qwiic-to-TRRS assembly

Length: 12 cm

TRRS jack: <https://lcsc.com/product-detail/Audio-Connectors_XKB-Connectivity-PJ-31640_C2879830.html>

|TRRS|Qwiic|
|----|-----|
|Sleeve| GND|
|Sleeve-side Ring| 3.3V|
|Tip-side Ring| SCL|
|Tip| SCA|

# Qwiic-to-FFC adapter

FFC connector for Azoteq: <https://www.lcsc.com/product-detail/FFC-FPC-Connectors_AFC11-S06ICA-00_C262496.html>

FFC connector for Cirque: <https://www.lcsc.com/product-detail/FFC-FPC-Connectors_JUSHUO-AFC11-S12ICA-00_C262499.html>

Single IDC contact: <https://www.digikey.com/en/products/detail/avx-corporation/709176001443006/3074530>

The FFC should be A-A type.

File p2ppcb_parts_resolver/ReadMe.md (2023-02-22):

# p2ppcb_parts_resolver

**p2ppcb_parts_resolver** is a Python library for P2PPCB Composer F360 (PC0).

p2ppcb_parts_resolver is independent of Autodesk Fusion 360 (F360), but designed to work with it.
The independence is mainly for debugging, and good for porting PC0 to other 3D CADs.

p2ppcb_parts_resolver resolves the names of the **design files**, the **part parameter set**, and the **specifier** of the parts of a key.
The key is represented in a KLE file and annotated with a **part description** set.

## Part parameter set and design file

Many 3D CADs have a parametric modeling feature. Using this feature, a design can represent many fixed forms.
In other words, a design file with a parameter set is equivalent to a fixed form.

## Part description

Usually this is a string that indicates the type of a part, e.g. "Cherry-style plate mount", "DSA", "Choc V2".
**Decal** or **Wiring** is a different story, but it is an exception.

## From KLE file to pattern name

A KLE file doesn't contain names like "ISO Enter" or "2u", but of course we can spot such name of a key in a KLE file.
p2ppcb_parts_resolver does. The spotted name is a **pattern name**.

## Specifier

In some cases, a pattern name with a part description set is enough to resolve everything. But there are other cases.
For example, row-dependent caps (Cherry, OEM, etc.) require row information. The information should be written in the "Profile / Row" of a KLE file.
A specifier consists of a "Profile / Row" string (or something similar) and a pattern name, e.g. "R4 2u" (Backspace) or "R1 2u" (Numpad 0).

## Overview of the resolving chain

- a KLE file and a part description set -> (iteration over keys)

    -  key -> 

        - "Profile / Row" string (or something similar)
        - pattern name

    - -> specifier ->

        - design file name of each part
        - parameter set

This is just an overview. There are many details.

## How to write the resolving rule

Look in the `p2ppcb_part_data_f360/parameters` directory. The root is `descriptions.csv`. It will look straightforward.
Let's go along DSA cap, `Cap,DSA,dsa` row.

Look in the `dsa` directory (the directory name is specified in the `Cap,DSA,dsa` row), and open `mapping.csv`.
You can see that the file maps the specifiers to their design file names and parameter name sets.

```
1u,DSA Keycap 1u v4.f3d,Travel
\d*u,DSA Keycap v8.f3d,Width Travel
```

Row order is important. The `Specifier` column is a regular expression, and `\d*u` matches "1u".
But p2ppcb_parts_resolver searches for matching rows from top to bottom. Once a row matches,
it stops searching. Specifier "1u" matches the `1u` row, and the `\d*u` row is ignored.

Let's go with "2u". The `\d*u` row hits, so the design file name is `DSA Keycap v8.f3d`, and the parameter name set is `Width Travel`.
We need to resolve these parameters and pass them to `DSA Keycap v8.f3d`. To do this, p2ppcb_parts_resolver looks at the CSV files in the directory.
Open `height.csv`, look at the top row, and find no `Width` or `Travel`. OK, `homing.csv`, no hit again. OK, `switch_x_y_angle.csv`...
Finally, p2ppcb_parts_resolver goes to the parent directory. Open `cap.csv`, and find `Width`, but specifier `2u` doesn't match.
`cap_wide.csv`, and find it. `Width` of "2u" is `37 mm`. Done. p2ppcb_parts_resolver resolved `Width`.

But, what is `ParameterA` in `cap_wide.csv`? We don't need it here. Also, we haven't seen `Travel` is resolved yet,
while there are no more CSV files to see.

This is the name of the game.

`ParameterA` is the parameter for stabilizers. On the other hand, `Travel` should be resolved while resolving a switch.
p2ppcb_parts_resolver makes *a parameter set*. `ParameterA` and the value `23.8 mm` will be added to the parameter set,
even it is not for `DSA Keycap v8.f3d`.

## Special parameters for part_z_pos

Key parts are stacked vertically (Z-direction). The reference level depends on the keyboard design. p2ppcb_parts_resolver
also resolves this.

- Cap: `TopHeight`, `CapStemBottomHeight`
- Switch: `SwitchStemBottomHeight`, `SwitchBottomHeight`, `Travel`
- Stabilizer: `StabilizerStemBottomHeight`

Using these special parameters and the alignment type (`StemBottom` or `TravelBottom`), p2ppcb_parts_resolver resolves
the Z position of each part in a key assembly.

## Special parameters for switch_xya

The angle, x, and y of a switch/stabilizer/PCB depends on the specifier.
For example, ISO Enter often requires a right-angled switch/stabilizer/PCB.
These are special parameters for this purpose:

- SwitchAngle
- SwitchX
- SwitchY
- StabilizerAngle
- StabilizerX
- StabilizerY

A PCB follows its switch, of course.

## Special parameter: `Placeholder`

`Placeholder` is another special parameter. All design files should have placeholder bodies.
These bodies should be tagged as placeholder, and the tag should have a string value that denotes the detail.
`Placeholder` value is `Placeholder` by default implicitly. You can write explicitly when you need to select a placeholder in a design file.

## Decal and Wiring

These are not parts, but they have part-dependent parameters.

Decal is a feature of F360. We need to adjust the decal parameters to fit each cap type and specifier.
Wiring is for route data generation. See PC0 source code for details.

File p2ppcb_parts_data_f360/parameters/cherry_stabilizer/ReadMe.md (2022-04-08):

# Cherry-style Stabilizer

You can combine this with a Choc V2 switch, by changing the switch orientation to `Right`.
In this case, you should scrape off the interfering part of the stabilizer post.

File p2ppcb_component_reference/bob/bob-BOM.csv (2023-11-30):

Reference | Quantity | Value
C1 C2 | 2 | 100n | https://lcsc.com/product-detail/Multilayer-Ceramic-Capacitors-MLCC-SMD-SMT_YAGEO-CC0402KRX7R6BB104_C309458.html
J1 | 1 | PinHeader_01x05 | https://lcsc.com/product-detail/Pin-Headers_HCTL-PZ254-1-05-Z-8-5_C2894928.html
J2 | 1 | STMM-115-02-L-D | https://lcsc.com/product-detail/IDC-Connectors_Wcon-3111-30SG0BK00T1_C783804.html
U1 | 1 | Pico | https://www.mouser.com/ProductDetail/SparkFun/DEV-17829
U2 U3 | 2 | 74HC164 | https://www.mouser.jp/ProductDetail/Texas-Instruments/SN74HCS164QBQARQ1?qs=iLbezkQI%252Bsg0rKdJotl1HQ%3D%3D

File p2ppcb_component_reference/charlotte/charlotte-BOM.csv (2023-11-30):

Reference | Quantity | Value
C1 C2 C3 C4 C5 | 5 | 100n | https://lcsc.com/product-detail/Multilayer-Ceramic-Capacitors-MLCC-SMD-SMT_YAGEO-CC0402KRX7R6BB104_C309458.html
D1 | 1 | CMOZ2L2TR | https://www.lcsc.com/product-detail/Zener-Diodes_ROHM-Semicon-EDZVT2R2-2B_C209611.html
IC1 IC2 IC3 | 3 | IS31LT3178-STLS4-TR | https://www.mouser.com/ProductDetail/Lumissil/IS31LT3178-STLS4-TR?qs=BJlw7L4Cy78FU6Gw58J21g%3D%3D
J1 | 1 | PinHeader_01x05 | https://lcsc.com/product-detail/Pin-Headers_HCTL-PZ254-1-05-Z-8-5_C2894928.html
J2 | 1 | Conn_02x18_Top_Bottom | https://lcsc.com/product-detail/IDC-Connectors_Wcon-3111-36SG0BK00T1_C920868.html
J3 | 1 | BM04B-SRSS-TB(LF)(SN) | https://lcsc.com/product-detail/Wire-To-Board-Wire-To-Wire-Connector_HCTL-HC-1-0-4PLT_C2845372.html
R1 R2 R3 | 3 | 80k | https://lcsc.com/product-detail/Chip-Resistor-Surface-Mount_YAGEO-RC0402JR-0782KL_C137836.html
R4 | 1 | 10k | https://lcsc.com/product-detail/Chip-Resistor-Surface-Mount_YAGEO-RC0402JR-0710KL_C60489.html
R5 R6 R7 | 3 | 47k | https://lcsc.com/product-detail/Chip-Resistor-Surface-Mount_YAGEO-AC0402JR-0747KL_C144710.html
R8 | 1 | 50 | https://lcsc.com/product-detail/Chip-Resistor-Surface-Mount_YAGEO-AC0402JR-0751RL_C227391.html
U1 | 1 | Pico | https://www.mouser.com/ProductDetail/SparkFun/DEV-17829
U2 U3 | 2 | 74HC164 | https://www.mouser.jp/ProductDetail/Texas-Instruments/SN74HCS164QBQARQ1?qs=iLbezkQI%252Bsg0rKdJotl1HQ%3D%3D
U4 | 1 | TS3A4751RGYR | https://lcsc.com/product-detail/Analog-Switches-Multiplexers_Texas-Instruments-TS3A4751RGYR_C130082.html

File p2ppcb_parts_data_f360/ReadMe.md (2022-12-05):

# p2ppcb_parts_data

See `p2ppcb_parts_resolver`'s `ReadMe.md`.

## `UseStabilizer` parameter

It just shows as the name. If the value exists and is nonzero, it is true.

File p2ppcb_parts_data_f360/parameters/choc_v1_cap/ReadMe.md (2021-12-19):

# Choc V1 Cap

`CapStemBottomHeight` is based on stabilizers' stem.

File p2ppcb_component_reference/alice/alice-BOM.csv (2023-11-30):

Reference | Quantity | Value | Substituted part
C1 C3 C4 C5 C6 C7 C8 C9 C10 C11 C17 C18 C22 | 13 | 100n |  | https://www.digikey.com/product-detail/en/yageo/CC0402KRX7R6BB104/311-1345-1-ND/2103129
C12 | 1 | 10n |  | https://www.digikey.com/product-detail/en/yageo/CC0402KRX7R7BB103/311-1042-1-ND/302959
C2 C13 C14 C19 | 4 | 4.7u |  | https://www.digikey.com/product-detail/en/yageo/CC0402KRX5R5BB475/311-3476-1-ND/7164497
C15 | 1 | 1u |  | https://www.digikey.com/product-detail/en/yageo/CC0402KRX5R5BB105/311-1438-1-ND/2833744
C16 | 1 | 2.2u |  | https://www.digikey.com/product-detail/en/yageo/CC0402KRX5R6BB225/311-1686-1-ND/5195588
C20 C21 | 2 | 47p |  | https://www.digikey.com/product-detail/en/yageo/CC0402JRNPO9BN470/311-1021-1-ND/302938
D1 | 1 | CMOZ2L2TR |  | https://www.digikey.com/product-detail/en/central-semiconductor-corp/CMOZ2L2-TR-PBFREE/1514-CMOZ2L2TRPBFREECT-ND/5211364
D2 | 1 | BAT60JFILM | * | https://www.digikey.com/en/products/detail/nexperia-usa-inc/PMEG2010EA135/2780240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
J1 | 1 | COLS |  | https://www.aliexpress.com/item/32676568854.html?spm=2114.12010612.8148356.63.76d42bfdmlM1SD
J2 | 1 | ROWS |  | https://www.aliexpress.com/item/32675338804.html?spm=2114.12010612.8148356.65.2892d4f7k8DH4p
J3 | 1 | USB_C_Receptacle_USB2.0 |  | https://www.digikey.com/product-detail/en/gct/USB4085-GF-A/2073-USB4085-GF-ACT-ND/9859733
J4 | 1 | SWD_USART_RGBDI_BOOT0 |  | https://www.aliexpress.com/item/32675338804.html?spm=2114.12010612.8148356.65.2892d4f7k8DH4p
J5 | 1 | I2C |  | https://www.digikey.com/product-detail/en/jst-sales-america-inc/BM04B-SRSS-TB-LF-SN/455-1790-1-ND/926861
R1 R2 | 2 | 10k |  | https://www.digikey.com/product-detail/en/yageo/RC0402JR-0710KL/311-10KJRCT-ND/729365
R3 R8 R9 | 3 | 1k |  | https://www.digikey.com/product-detail/en/yageo/RC0402JR-071KL/311-1-0KJRCT-ND/729355
R4 R5 | 2 | 5.1k |  | https://www.digikey.com/products/en/resistors/chip-resistor-surface-mount/52?k=yageo+RC0402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
R6 R7 R10 R11 | 4 | 22 |  | https://www.digikey.com/product-detail/en/yageo/RC0402JR-0722RP/YAG1285CT-ND/4935398
RN1 RN2 RN3 | 3 | 10k |  | https://www.digikey.com/product-detail/en/cts-resistor-products/746X101103JP/746X101103JPCT-ND/1118444
RN4 | 1 | 47k |  | https://www.digikey.com/product-detail/en/cts-resistor-products/746X101473JP/746X101473JPCT-ND/1118431
SW1 | 1 | Omron_B3FS |  | https://www.digikey.com/product-detail/en/omron-electronics-inc-emc-div/B3FS-1012P/SW1237CT-ND/2747253
U1 U2 U4 | 3 | 74HC165 |  | https://www.digikey.com/product-detail/en/nexperia-usa-inc/74HC165BQ-115/1727-6032-1-ND/2753868
U10 | 1 | STP08CP05 |  | https://www.digikey.com/en/products/detail/stmicroelectronics/STP08CP05XTTR/1702997
U3 | 1 | 74HC02BQ,115 |  | https://www.digikey.com/product-detail/en/nexperia-usa-inc/74HC02BQ-115/1727-4525-1-ND/2530902
U5 | 1 | STM32F072C8Ux |  | https://www.digikey.com/product-detail/en/stmicroelectronics/STM32F072C8U6/497-17360-ND/5051283
U6 | 1 | USBLC6-2P6 |  | https://www.digikey.com/product-detail/en/stmicroelectronics/USBLC6-2P6/497-5026-1-ND/1007464
U7 | 1 | SN74LV1T34DCK |  | https://www.digikey.com/product-detail/en/texas-instruments/SN74LV1T34DCKR/296-37177-1-ND/4555594
U8 | 1 | TLV75533PDRVR | * | https://www.digikey.com/en/products/detail/texas-instruments/TPS74533PQWDRVRQ1/11308854
U9 | 1 | TS3A4751RGYR |  | https://www.digikey.com/product-detail/en/texas-instruments/TS3A4751RGYR/296-24477-1-ND/2057705

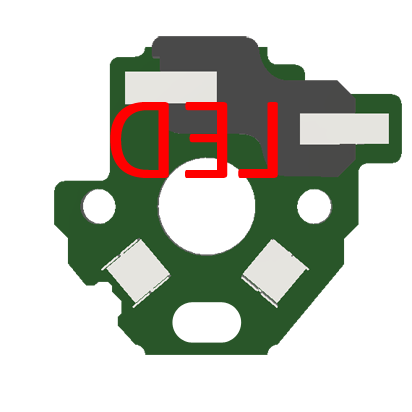
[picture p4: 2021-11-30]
p2ppcb_parts_data_f360/png/PCB-Choc-LED.png

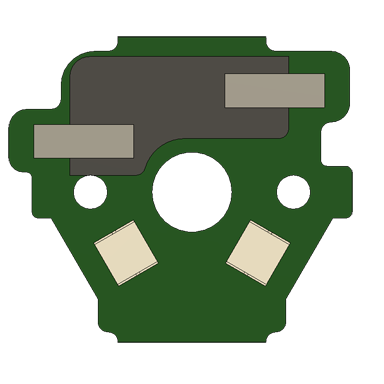
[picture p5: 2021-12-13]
p2ppcb_parts_data_f360/png/PCB-MX.png

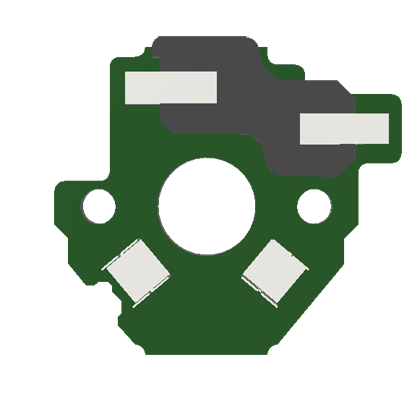
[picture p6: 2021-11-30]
p2ppcb_parts_data_f360/png/PCB-Choc.png

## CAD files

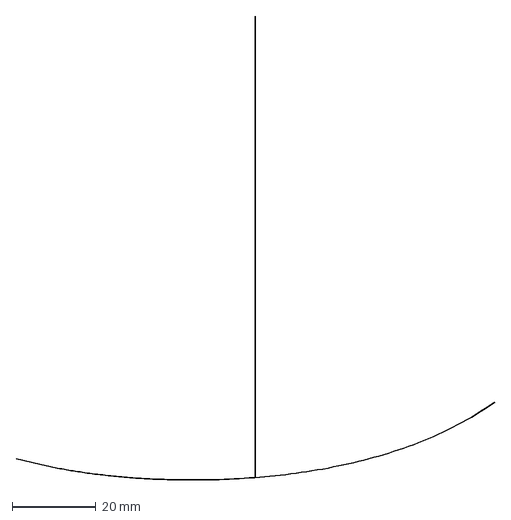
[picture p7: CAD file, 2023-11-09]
p2ppcb_composer_f360/scaffold_data/skeleton.dxf
114.0 x 110.6 mm

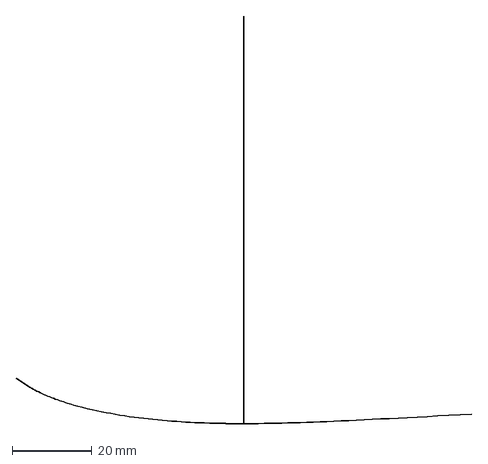
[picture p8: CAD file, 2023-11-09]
p2ppcb_composer_f360/scaffold_data/alternative.dxf
114.0 x 102.0 mm

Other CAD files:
p2ppcb_component_reference/contact-to-socket/Single IDC Contact Push Mount.f3d
p2ppcb_composer_f360/f3d/Alice.f3d
p2ppcb_composer_f360/f3d/Bob.f3d
p2ppcb_composer_f360/f3d/Charlotte.f3d
p2ppcb_composer_f360/f3d/Foot.f3d
p2ppcb_composer_f360/f3d/TRRS Terminal.f3d
p2ppcb_composer_f360/f3d/appearance.f3d
p2ppcb_composer_f360/f3d/trackpad/Azoteq Qwiic-to-FFC.f3d
p2ppcb_composer_f360/f3d/trackpad/Azoteq TPS43.f3d
p2ppcb_composer_f360/f3d/trackpad/Azoteq TPS65.f3d
p2ppcb_composer_f360/f3d/trackpad/Cirque Qwiic-to-FFC.f3d
p2ppcb_composer_f360/f3d/trackpad/Cirque TM023023.f3d
p2ppcb_composer_f360/f3d/trackpad/Cirque TM035035.f3d
p2ppcb_composer_f360/f3d/trackpad/Cirque TM040040.f3d
p2ppcb_composer_f360/test_data/f3d/after_init.f3d
p2ppcb_composer_f360/test_data/f3d/fill_frame_oracle.f3d
p2ppcb_composer_f360/test_data/f3d/generate_scaffold_oracle.f3d
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

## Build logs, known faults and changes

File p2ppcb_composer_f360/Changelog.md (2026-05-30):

# Changelog

## [0.2.6] - 2026-05-30

- Announcement: P2PPCB platform will be abandoned in Jan 2027 if there is no demand.

## [0.2.5] - 2026-01-31

- Bug fix: Now F360 has "Part Design" and makes it as default of new design. Follows this change.

## [0.2.4] - 2026-01-23

- Follows F360 update.

## [0.2.3] - 2025-08-02

- Bug fix: Key enable/disable works now.
- Bug fix: Change Key command in multiple selection and editing Offset.

## [0.2.2] - 2025-07-25

- Gateron LP stabilizer design has been revised.
- Now [Choc V2 clip type stabilizer](https://keeb-on.com/products/stabilizer-chocv2) is available.
- Now key travel can be specified.
- Change Key command has been improved.

## [0.2.1] - 2025-06-19

- PCB snap design has been revised.
- Full feature for macOS.
- Decal RPA has been removed and replaced by API.
- New feature in Assign Matrix command: You can find unassigned key easily by showing yellow X.
- Bug fix: Now separated frames have correct body name.

## [0.1.2] - 2025-01-29

- Now it looks stable enough to track changelog.
- Dependencies to died libraries are replaced to living libraries. cefpython -> cef-capi-py, Python-MIP -> PuLP.
- Minor bug fixes.

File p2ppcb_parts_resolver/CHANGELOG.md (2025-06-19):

# Changelog

## [0.1.13] - 2025-06-19

- Adds separate process feature in `resolve_kle()`.

## [0.1.12] - 2025-01-23

- Runs with latest dependencies.
- Changelog style has been changed.

## [0.1.11] - 2023-07-25

- `resolve_kle()` without image is available now. It doesn't require `kle-scraper` too.

## [0.1.10] - 2022-05-25

- Special parameters `Stabilizer[X|Y|Angle]` added.

## [0.1.9] - 2022-05-01

- `StabilizerTravel` added. Now stabilizer's `z_pos` is adjusted by travel bottom.

## [0.1.8] - 2022-02-01

- Now `OccurrenceParameter` holds `i_kle`.

## [0.1.7] - 2022-01-20

- The return type of `resolve_kle()` has been modified.

## [0.1.6] - 2021-12-20

- Special parameters `SwitchAngle`, `SwitchX`, and `SwitchY` are added. Now `resolve_specifier()` returns
`switch_xya`.

## [0.1.5] - 2021-12-19

- Spacebar width threshold has been changed to 5u.
- Now `Placeholder` parameter is collected as a special parameter.

## [0.1.4] - 2021-12-13

- Initial release

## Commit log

2021-11-30 from local
    [Alice.f3d, Choc v2 v22.f3d, DSA ISO Enter v6.f3d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]
2022-04-08 Screw hole 1.71mm -> 1.6mm
    [Bob.f3d, Charlotte.f3d]
2022-05-01 StabilizerTravel added.
    [MX Cherry-style plate mount Stabilizer 2u.f3d, MX Cherry-style plate mount Stabilizer 6u.f3d, height.csv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]
2023-12-21 fix decal
    [mapping.csv, pointer_offset.csv, single.csv]
2024-01-10 working on trackpad Set Attribute bug fix
    [Azoteq Qwiic-to-FFC.f3d, Azoteq TPS43.f3d, Azoteq TPS65.f3d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]
2024-01-19 Gateron LP wiring trackpad F3D route generation with locator enable/disable
    [Azoteq TPS43.f3d, Azoteq TPS65.f3d, Cirque TM023023.f3d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]
2024-01-22 add bosses
    [Cover Adjust Boss Reverse.f3d, Cover Adjust Boss.f3d, Cover Bottom Boss.f3d]
2024-04-05 New feature: Insert MIsc command and F3Ds for the command - Trackpad (Azoteq, Cirque) - TRRS terminal Bug fix: - Set Attribute command - Handling of disabled keys in Route command - Gateron LP now OK
    [Azoteq Qwiic-to-FFC.f3d, Azoteq TPS43.f3d, Azoteq TPS65.f3d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]
2024-04-15 Now the decals of keycap is more robust to the display scaling, but not very good yet.
    [mapping.csv, pointer_offset.csv, single.csv]
2025-02-25 PCB snap design has been adjusted.
    [PCB Choc v15.f3d, PCB Gateron LP v13.f3d, PCB MX v17.f3d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]
2025-06-13 Separated frames have correct body name Better PCB snap
    [PCB Choc v14.f3d, PCB Gateron LP v13.f3d, PCB Gateron LP v15.f3d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]
2025-06-17 Decal adjust
    [single.csv, two_row_enter.csv]
2025-07-25 - Choc V2 Stabilizer plate-mount added. - Gateron LP Stabilizer adjusted.
    [Choc v2 Stabilizer v8.f3d, Choc v2 v31.f3d, Choc v2 v33.f3d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]
2025-07-25 Document update
    [description.csv]
2025-08-15 Bug fix: Check Key Assembly command went wrong when travel is "Default".
2025-08-27 Choc V2 adjusted
    [Choc v2 v33.f3d, Choc v2 v34.f3d, mapping.csv]
